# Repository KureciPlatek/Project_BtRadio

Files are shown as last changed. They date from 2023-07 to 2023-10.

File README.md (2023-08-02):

# Vintage radio Philips Hurricane De Luxe with Bluetooth

This project is about renewing an old (and wonderful) Phillips Hurricane De Luxe 50IC361.
It still uses loudspeaker, but inside is everything new. It becomes new and modern audio stream source

The aim is also to have fun with new technologies and train HW/SW skills as well as project management. 

## The radio:  
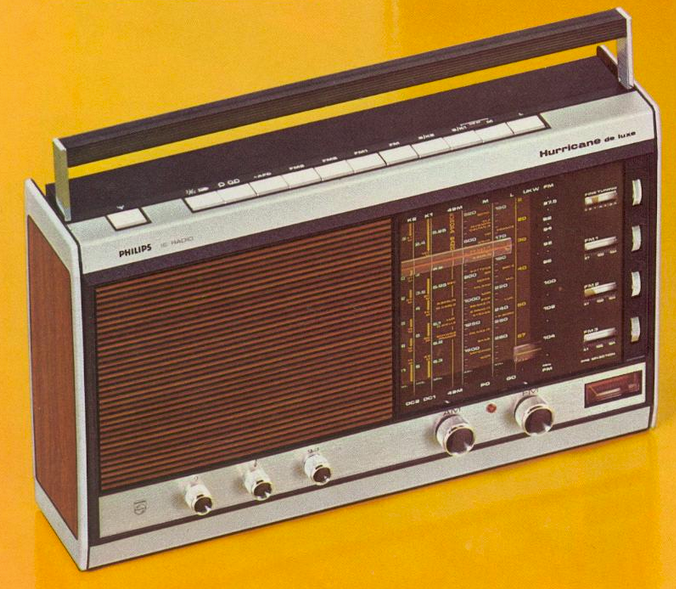
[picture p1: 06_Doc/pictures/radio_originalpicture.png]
Philips Hurricane de Luxe Philips 50IC360


## Technology used:  
- Bluetooth chip RN52 (old but had it on a shelf that was getting dust for years)
- FM demodulator from Silicon Labs: si470x which is able to demodulate FM radio emission and decode RDS (Radio Data System)
- Epaper 5.8" from Waveshare, they actually fit almost perfectly where frequency panel was
- Rotary encoders to give "digital" signals to central/control unit
- RP2040 as central unit because it is cheap, has double core features and suits perfectly the need of this project
- KiCad for HW development
- CMake/Pico SDK for software development
- git for versionning and project management
- Use ARC42 documentation format to present project and explain architecture

For the management part, full development is managed with a TICKETS.md textual file. It is split into 3 parts: SYS, HW and SW: SYStem, HardWare and SoftWare. No particular mechanical development was done so no section for that is made (it could exists to interface PCB into old Phillips radio though).

All details here:
- Introduction, goals and constraints: [ARC42_IntroAndGoals](./00_Requirements_Inputs/ARC42_IntroAndGoals.md)
- Contextes and solution strategy: [ARC42_SolStrat](./01_Analysis/ARC42_ContextAndScope.md)
- Architecture description: [ARC42_Architecture](./02_Architecture_Modelisation/ARC42_architectureMain.md)
- Project decisions, risks and technical debts: [ARC42_DecisionsRisksDebts](./02_Architecture_Modelisation/ARC42_RiskDebtDecisions.md)

## Required:

- Raspberry pico sdk
- cmake
- gnu c compiler toolsuite

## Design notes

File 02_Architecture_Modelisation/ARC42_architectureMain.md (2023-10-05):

# Architecture description

This chapter describes the main architecture, first as a system view, complying to all requirement, quality goals and constraints.
Then it is split into Software, Hardware and Mechanical topics and architectures.

All issues and tickets about hardware and software topics are listed in [TICKETS](../00_Requirements_Inputs/TICKETS.md) file. As mechanical topics are rare and don't require many effort. No mechanical tickets are written.

## System architecture structure design

System architecture

|Module| Purpose/Description| Interface|Technology| Nickname |
|:-:|:-|:-|:-|:-|
|Central Unit| Contains the software, interfaces almost all other modules and is the main entity of this system| All possible interfaces needed by other modules | RP2040 on a Raspberry Pico board | CU |
|Rotary encoders| Button interfaces with human. They can forward human commands to central unit: turned direct, turned indirect or pushed (they possess a push button too.). This module also gathers legacy push-buttons of radio which will be re-used to select radio mode | GPIOs are required, 3 per Rotary Encoder | Iduino Rotary Encoders |RE |
|Bluetooth Chip| Provide a Bluetooth connection to audio stream sources, retrieve information about connected device and track metadata and provide an audio differential output | GPIOs and UART are needed to control this device | RN52 | BT|
|FM demodulator | Can demodulate FM radiowaves and provide the audio output. It is also able to decode RDS metadata| I2C and UART are required to control this device | si470x| FM|
|e-paper screen| Is used to print all info, status, any kind of output judged as relevant for human user. Like track metadata, FM status or BT status | SPI is required | Waveshare e-paper 5.83" | EP |
|Audio Stage| Drives the 8 Ohms loudspeaker and switches between FM and BT modules depending on what CU orders | One GPIO is required | TPA6112A, PMA8302, TS5A2234 | AS |
|Power Management| Provide power supply to system. Is able to generate a 3.3V from either a 5V power supply, or a 12V power supply (battery)| USB plug and wires | LM317, NXE2S1205MC DC-DC converter |PM|
|Auxiliary Connector| Most of modules have debug interfaces as well as additional interfaces available. They are all gathered here, for future purpose if needed. SWD and UART of RP2040 are available here for debug| SPI, UART, GPIOs | Simple headers | AUX |

**Note:** This system view is also deploymen-view like. Therefore, no deployment view will be described in further documentation.

## Software architecture structure view

The software structural architecture is quite straigth-forward, as it doesn't have any particular complexity. Therefore, a simple layer architecture is quite enough:  

Software architecture

Modules Pico SDK and RP2040 Hardware are actually "out of project" as they are already made, external modules. They are part of the structural architecture, but no work is to be done here.

### Detailled description of modules:

|Module| Desription| Software directory |
|:-:|:-|:-|
|Application (main)| main module, (starts with main.c in program). Describes the wished radio behavior and uses the other modules beneath it to realize it | [Software/code](../03_Development/Software/code/) |
|re_Buttons| Driver for rotary encoders, it provides handles to whom want to be notified if a rotary encoder was turn, in which direction it was turned and if push button was triggered. For legacy buttons, as only a direct GPIO state is enough, no code was added for them. They will be monitored directly by the Application (main module) | [Software/code/re_Buttons](../03_Development/Software/code/re_Buttons/) |
|bt_rn52| Driver for Bluetooth chip Microchip's RN52. It uses UART and GPIOs to configure the RN52 chip, send command and read results. I2S inteface is not used. Audio stream is directly outputed to differential output | [Software/code/bt_rn52](../03_Development/Software/code/bt_rn52/)|
|fm_si470x| Driver of si470x chip, which provides FM demodulation. It uses I2C and GPIOs interfaces to configure, control and retrieve RDS data from Si470x chip |[Software/code/fm_si470x](../03_Development/Software/code/fm_si470x/)|
|rdsDecoder| Provide tools to decode RDS frames notified by si470x. This module is actually only used by fm_si470x module and may be integrated to it |[Software/code/rdsDecoder](../03_Development/Software/code/rdsDecoder/)|
|hmi_ePaper| Driver of Waveshare e-paper. It mainly uses already provided driver from waveshare, which was a little bit reconfigured and cleaned for lightness and simplicity |[Software/code/hmi_ePaper](../03_Development/Software/code/hmi_ePaper/)|

**Note:**  
The whole code is written in C and uses CMake for compilation.

## Software architecture runtime view

This chapter describes, either with sequence, process or state machine UML diagrams, module's behavior as well as application's usecase.

### Application usecases

Rotary encoders allow infinte turn in direct or indirect rotating direction. Two rotary encoders are used for functional requirements described in [Intro and goals](../00_Requirements_Inputs/ARC42_IntroAndGoals.md).  
Depending on the mode (Bluetooth stream or FM stream) both of those rotary encoders enters a different behavior.  
The whole application runs as a state machine, depending on which mode is active (audio stream or FM demodulation). It is a simple state machine switching between mode BT (Bluetooth) and FM (FM demodulator). How user interacts with radio and how radio reacts is described below:  

#### Buttons and rotary encoders

**[Usecase 1 - standard audio stream control](../00_Requirements_Inputs/ARC42_IntroAndGoals.md)**  
**[Usecase 4 - Seek FM station](../00_Requirements_Inputs/ARC42_IntroAndGoals.md)**  

|Rotary encoder| Mode | Direct rotation | Indirect rotation | Push button |
|:-:|:-:|:-:|:-:|:-:|
|RE_1| Bluetooth | Volume- | Volume+ | Mute/Unmute |
|RE_1|FM demodulation| Same | Same | Same |
|RE_2| Bluetooth | Previous track | Next track | Play/Pause |
|RE_2|FM demodulation| Previous Station | Next Station | Select favorite ([behavior here](#select-favorite-fm-channel)) |

**[Usecase 2 - connect modern device](../00_Requirements_Inputs/ARC42_IntroAndGoals.md)**  
Phillips radio has many push buttons on top of it. Some are push/hold/exclude, some are just push/hold and some are just push.

Button | Place | Style | Role |
|:-:|:-:|:-:|:-:|
|X    | Far left | Push/Hold/exclude | Select bluetooth streaming |
|IX   | | Push/Hold/exclude| Select FM demodulation|
|VIII | | Push/Hold/exclude| none |
|VII  | | Push/Hold/exclude| none |
|VI   | | Push/Hold/exclude| none |
|V    | | Push/Hold/exclude| none |
|IV   | | Push/Hold/exclude| none |
|III  | | Push/Hold| none |
|II   | | Push/Hold| none |
|I    | Far right | Push Hold| On/Off |

**[Usecase 3 - Select and save FM station](../00_Requirements_Inputs/ARC42_IntroAndGoals.md)**  
Rotary encoder 2 has a specificity when entering "Select Favorite". There are many different stations and be able to select a favorite is nice. Saving a favorite should be possible, as station differs from place to place.

When clicking PushButton of RE_2 in FM mode, the following behavior appears:  
Behavior select and save FM station

### FM behavioral

@todo - also may need a bugfix when seeking/tuning and so on

### BT behavioral

No particular behavioral, look at doxygen API documentation

### RE behavioral

Rotary encoders work as state machines. As soon as one of the input of rotary encoder is triggered (GPIO_A or GPIO_B), they will enter a "wait for the other input to determine direction":  

Rotary encoder behavior

### EP behavioral

[< prev (Context and scope)](../01_Analysis/ARC42_ContextAndScope.md) - [next > (Decision, Risks and Technical debt)](../02_Architecture_Modelisation/ARC42_RiskDebtDecisions.md)

## Hardware architecture view

This section provides a detailled view of circuit schematic and PCB design. There is no behavioral described, as it may be found in the corresponding datasheet of components and will only be a re-write of what already exists.

### Schematic

Schematic is divided into thre sheets: a main sheet with modules. An audio amplifiying stage sheet and a connectors to legacy push buttons sheet.

#### Main schematic
Main schematic

#### Audio amplification stage schematic
Audio stage

#### Legacy push buttons connectors schematic
Legacy push buttons

### PCB
After routing, PCB has the following face:  

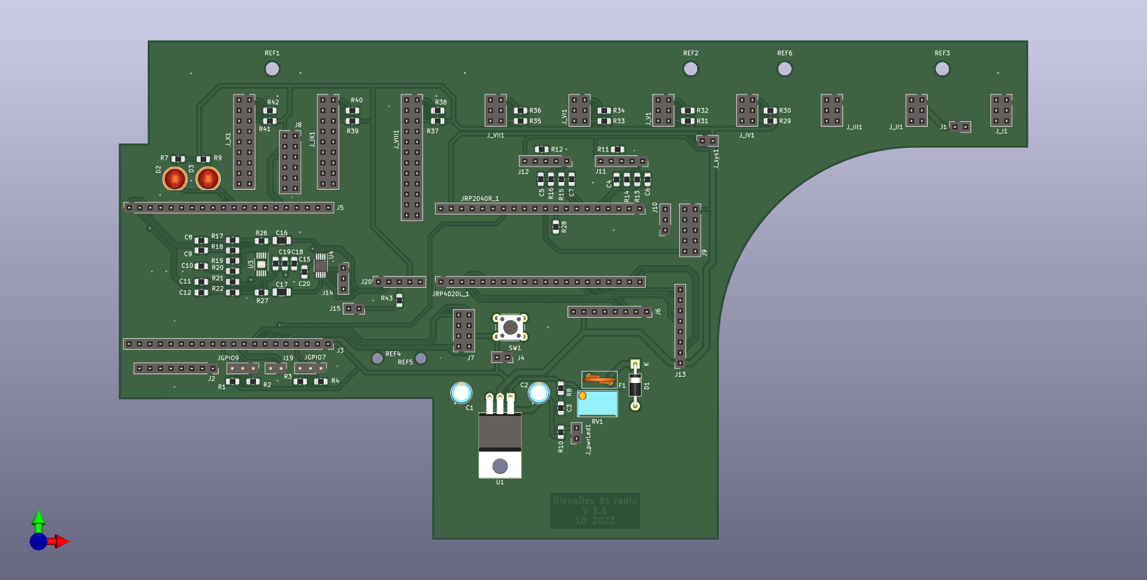
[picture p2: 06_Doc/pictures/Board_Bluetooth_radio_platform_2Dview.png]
PCB 2D view


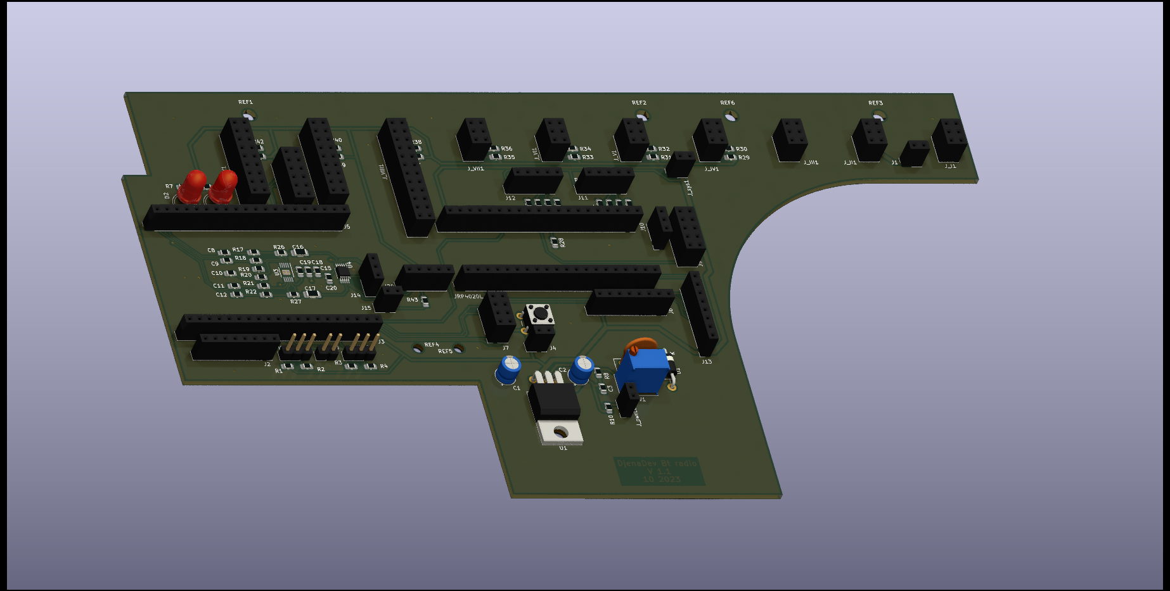
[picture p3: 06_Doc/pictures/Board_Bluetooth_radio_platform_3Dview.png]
PCB 3D view


@todo: holes, form and connectors placement dimension measure list.

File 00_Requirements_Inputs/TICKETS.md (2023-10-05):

# Project Bluetooth radio

## INTRO:

In this file are listed all tickets/todo to be checked and done. Another program should be used but it will suffice for now.

It is sorted by:

|level|description|Identification prefix|comments|
|:-:|:-|:-:|:-|
|system|means application, behavior, user experience, non technical topics|SYS_||
|software|pure software, can be bare metal, like driver, to scheduling items|SFW_||
|hardware|everything that is outside the DSP and are linked to electronic development|HDW_||

*__Note:__  
the issue identification is a prefix followed by a number which is the issue identification number.   
For example: SYS_14 is the system level issue 14*

*__Note:__  
When closing an issue (rejected or resolved), please add the SHA-1 number from git to identify it and track it back.*

***
## SYSTEM ISSUES

**New issues:**  

|Issue| Description | state |
|-|-|-|
|SYS_13| *Architecture* Add clean doxygen API documentation of drivers to architecture documentation |NEW|
|SYS_15| *Architecture* Add add link to requirements/constraints, everywhere in project description |NEW|

**Work In Progress issues:**  

|Issue| Description | state |
|-|-|-|
|SYS_11| *System* Integrate all (obviously) | WIP - Breadboard done, integration of RE, BT and EP done. FM module will be deactivated at the beginning |
|SYS_12| *Architecture* Write down all algorithms and interrupt routines in UML diagrams/pseudo code |NEW|

**Resolved issues:**

|Issue| Description | state |
|-|-|-|
|SYS_3| *FM tuner* Check for a good AM/FM demodulator, some integrate RDS and RBDS, like Si4703 (look for Sparkfun breakout board) | DONE - use of Si4703 breakout board |  
|SYS_6| *HMI* Use of ePaper screen with RP2040 Pico https://www.berrybase.de/5-83-zoll-e-ink-display-modul-fuer-raspberry-pi-pico-648-480-schwarz/weiss | DONE |
|SYS_2| *Multiple PCB project* As some Bluetooth radio may stay on furnitures, like the vintage one, a direct plug to 220V network and a stronger audio amplifier is possible. How to manage two kind of PCB should be decided | DONE - create two PCBs |
|SYS_7| *Audio amplification* Check if Class D is sufficient and remove the TPA6112A2 | DONE - keep TPA6112A2 as it is wonderfully powerful with it |
|SYS_4| *HMI* List all input and features that system shall have: AM/FM switch, Bluetooth pair and connect, maybe a small screen | DONE - AM/FM in option, rest is all integrated |
|SYS_5| *HMI* Test and assignate available push button and rotary button of Phillips to interface of RN52 | DONE - Look at document  Architecture->Behavioral->hmi_description.md |
|SYS_8| *Project versioning* Add a github repository | DONE - but lose of old git repo history |
|SYS_14| *Architecture* Add application main usecases and link them to runtime view of software architecture |DONE - Add of Usecase diagram and its corresponding behavioral diagrams|
|SYS_9| *HMI* Check that buttons of Phillips radio are good: maybe button on far right is just push and not push/hold | DONE - Button on far right is only push but not hold. Start of radio is now on main button II |

**Rejected issues**

|Issue| Description | state |
|-|-|-|
|SYS_1| *Use of a battery* To use the radio without any power supply, a battery must be added. It implies however some constraints on the available voltage on the PCB. This limits the choice of audio amplifier available. Create a votlage which is bigger than the one from power supply is quite complex and may lead to development complexity | REJECTED - Too complex for Mark I futur use: RP2040 Plus Based (contains a Lithium manager) |
|SYS_8| *HMI* Add RealTime clock and Date for more infos on screen | REJECTED - will take too much time |
|SYS_9| *Memory* Add external flash like a W25Q16JV (SPI, 133 MHz) or an M25P16 (SPI, 75 MHz) | REJECTED - Should be fine without. Otherwise, our system is too complex |
|SYS_5| *Architecture* Create block diagram of main element with their interfaces | REJECTED - Carry on with project and get it done |
|SYS_10| *Proj_DVA* Add AD8248 circuit and PCB to project | REJECTED - one system at a time |

***
## SOFTWARE ISSUES

**New issues:**  

|Issue| Description | state |
|-|-|-|
|SFW_24 |*Doc* Cleanup and generate Doxygen API | NEW |
|SFW_29 |*FM_module* FM demodulator has a strange reaction to seek or tune and can't find any channel/station | NEW |

**Work In Progress issues:**  

|Issue| Description | state |
|-|-|-|
|SFW_14 |*FM_module* Add behavioral in application | WIP - half commented out |
|SFW_7 |*Architecture* Describe code as a waiting state machine to recieve "internal interrupts", which are tokens | WIP - partially implemented, they way inputs from modules are processed should be checked |
|SFW_3 |*Architecture* Cleanup git repo, create clean architecture of project | WIP - cleanup code for useless and commented lines |
|SFW_28| *BT_module*, *FM_module* Deactivate interrupts of module when not in use | WIP - only UART and GPIO interrupts are activable/deactivable |

**Resolved issues:**

|Issue| Description | state |
|-|-|-|
|SFW_1 |*e-Paper* Add test and interface to RpPico with assigned pins | DONE - use of example in /home/jeremiegallee/Pico_epaper_example/ |
|SFW_10 |*Coding* synchronize naming with architecture (prefixes) bt_rn52 for bluetooth module and fm_si470x for FM module, re for rotary encoders and epaper for HMI | DONE - set bt_, fm_, re_ and ep_ prefixes |
|SFW_8 |*BT mode* Create high level API to communicate with RN52 module through UART and AT commands | DONE - already implemented |
|SFW_18 |*FM mode* Restructure fm_application and fm_api as they have common role and SOLID principles not fully respected (call only from one place of the module, not 2) | DONE - renamed functions prototypes and file names |
|SFW_5 |*Architecture* Create main state machine and its sub state machines | DONE - Main state machine processes new inputs and execute corresponding actions |
|SFW_9 |*BT mode* Add feature to print "ready to pair", "connected" and so on to epaper screen | DONE - keep it simple and just check if connection bit of rn52 status registers is still set |
|SFW_25 |*EP_module* EP_module provided API can't load new lines and keep the old ones. Way to use it should be different | DONE - call Paint_ClearWindows() to clean one line only |
|SFW_4 |*Architecture* Create RotaryEncoder interrupts | DONE - Test success |
|SFW_13 | *BT mode* Add GPIO2 interrupt (which implies to send Q to radio) | DONE - Q is sent to RN52 after GPIO2 interrupt |
|SFW_15 | *Main* Take care of radio project init and selection of mode with GPIOs | DONE - GPIOS which requires interrupt are gathered together in hal_radio module |
|SFW_19 |*e-Paper* Add clean API for rest of the application | DONE |
|SFW_20 |*All* Make project compile. Maybe restart full project CMakes as they are strange | DONE - use simple CMake structure |
|SFW_16 |*REx* Add timeout before other GPIOs may "react". Aim is to entprellen | DONE - Not perfect but enough for requirements |
|SFW_21 |*RP2040* Check this stuff with double core. We may have pbm with interrupts affected to a core | DONE - Only core0 is called. Nothing on core1 right now |
|SFW_17 | *BT mode* Add processing function to analyse retrieved data from RN52's UART comm | DONE - RN52's comm had to be hugely cleaned up |
|SFW_27 |*EP_module* Check why is epaper having this cathodic tube like effect (imageBuffer not all 0?) | DONE - had to clean heap where image buffer was saved |
|SFW_26 |*EP_module* Add screenClear() procedure before shuting down. Otherwise, pixels will stay active and may damage epaper | DONE - Use of ep_deactivate() when no HW mode is selected |
|SFW_2 |*FM_module* Strange freeze after first seek up/down. Debug with PicoProbe | DONE - A too small array was given and it was overwriting out of bonds on the stack |

**Rejected issues**

|Issue| Description | state |
|-|-|-|
|SFW_12 |*FM mode* Manage FM as a handle too | REJECTED - use getters and setters instead |
|SFW_11 |*REx* Add delay between each rotary A or B key | REJECTED - Control of RE is not perfect but enough for now |
|SFW_22 |*RP2040* [Optional] use of FreeRTOS for multitasking | REJECTED - Do it in a second version |
|SFW_23 |*Structure* Modify and clean hal_main for GPIOs IRQ as it is too quick and dirty | REJECTED - Do it in a second version |

***
## HARDWARE ISSUES

**New issues:**  

|Issue| Description | state |
|-|-|-|

**Work In Progress issues:**  

|Issue| Description | state |
|-|-|-|

**Resolved issues:**

|Issue| Description | state |
|-|-|-|
|HDW_3| *Programming protection* To avoid too many components on board. Use of Waveshare USB to TTL. But it must be set to 3.3V because will be directly connected to RN52 power supply| DONE |
|HDW_2| *Programming interface* The RN52 must be programmed through an UART interface. The board must be disabled from voltage, so that only Waveshare USB to TTL may power the board and program it through UART | DONE - all RN52 boards to last firmware and UART connector added |
|HDW_9 | *Structure* Organize Kicad project into sheets, one sheet per module of board | DONE - use hierarchical sheet |
|HDW_12| *Class A audio amplifier* generate current driven class A audio amplifier circuit | DONE - but will be unused firstly |
|HDW_4 |*Board* create footprints for buttons of old Phillips radio | DONE - footprints are simple 2.57 mm pitch header footprints |
|HDW_14| *Structure* Rename all labels for a hierarchical and structured naming. Do it with sheets too | DONE |
|HDW_6 |*Board* Check for debug interface with RaspPico debug probe and BlackMagicProbe | DONE - Picoprobe will be used instead of BMS. So install Picoprobe connector with BMS style|
|HDW_8 |*Powersupply* Find circuit to connect to 220 VAC directly. It will provide the advantage to generate +5V, +3V3 and +30V for bigger audio amplifiers | DONE - Use an LM317 and buy/use a "good ol'" 12V power supply. RP2040 supplied through Vsys (main power input) |
|HDW_15| *Schematic* Add all values to passive R and C elements | DONE |
|HDW_10| *Housing* Create connectors for each button/selection on body housing | DONE - NO/NC connection are available on Phillips 50IC361 datasheet |
|HDW_16| *Schematic* Add e-paper display connector to board | DONE - subsheet created with connectors |
|HDW_18| *Schematic* Change power management symbols for ERC check success | DONE - change earth to GND symbol and issue lot of minor changes |
|HDW_20| *PCB* Check that all boards are well placed (direction of pins and connectors) as well as they have enough mechanic place | DONE - had to increase brightness of RN52 Sparkfun board |
|HDW_21| *PCB* Check size of holes for buttons header. Maybe the legacy component doesn't fin inside it | DONE - They fit, but only from one side |
|HDW_24| *PCB* Add name and version on board | DONE |
|HDW_17| *Schematic* Add list of elements that are not on PCB, like Jack barrel and heat sink | DONE - ordered heat sink and USB plug |
|HDW_23| *PCB* CHeck minimal via and wire brigthness allowed by JLCPCB | DONE - JLCPCB offers up to 0,127 mm wire thickness |
|HDW_33| *PCB* LM317: move so that it may be mounted horizontally | DONE - all pieces moved |
|HDW_32| *Powersupply* Put potentiometer for voltage regulator | DONE - added in schematic and PCB |
|HDW_31| *Powersupply* Add potential DC-DC downconverter for 12V battery pack | DONE - added in schematic and PCB |
|HDW_34| *PCB* Move all button resistance down to few mm as they will disturb mechanical place of button holders | DONE - all resistance moved |
|HDW_36| *PCB* Add boarder lines for cut | DONE - Had to remove fully drawn circle from edge.cut layer |
|HDW_25| *PCB* Install holes for screwing/monting on old radio | DONE - add mounting holes for PAM8302 too |
|HDW_38| *All* Fix UART communication wires. BT_Rx is actually on GPIO4 and BT_Tx on GPIO5 | DONE - modify schematic and PCB |
|HDW_41| *Routing* BT, EP and FM modules have been wrongly routed. Correct PCB and Software | DONE - changed communication lines of UART and I2C for BT, FM and EP modules |
|HDW_45| *Powersupply* Remove 12V transformer, go only on 5V | DONE - removed in schematic and PCB |
|HDW_39| *Schematic*  RP2040 actually has very low internal pull-up/down. 100k is way too high and signal at RP2040 pin is too small. Check pull-up and pull down resistance of 10k or 4,7k are ok | DONE - in commit 45d533c HDW_41 |
|HDW_44| *PCB* Check that push buttons are good, only on dry contact way, but check that a pushed button is either high or low active, without any perturbations | DONE - push buttons are gnd in normal position and to Vcc when pushed |
|HDW_42| *PCB* Move mechanical place of push buttons, they are biased of few millimeters, add a system to fix/set vertical place of mechanical buttons at production (set/adapt it at mounting) | DONE dimensions were measured on final target for mounting |
|HDW_50| *PCB* Check mechanical place of mounting screws if they fit to the right place | DONE mouhting screw are now in the right place mut may be small |
|HDW_49| *PCB* Check that mechanical place for eval-boards fits | DONE - all good |
|HDW_51| *Schematic* Change on/off button to connector II or more as I is not push/hold but just push | DONE - moved to push button II and update of PCB |
|HDW_54| *All* Update BOM and buy parts | DONE - had to change C15 and C16 from 0805 to 1210 footprints |
|HDW_53| *PCB* Modify layout of preamplifier and switch to improve gnd path | DONE - improved gnd panel and placement |
|HDW_55| *PCB* Improve grounding of F and B copper ground panes by connecting push buttons jumper unused vias to ground | DONE |
|HDW_37| *PCB* Send PCB to production, gather last required components, sold everything together | DONE - go to V1.1, V1.0 is not good |
|HDW_7 | *Audio ampl* Order and test the TS5A2234 analog audio switch | DONE - works fine |
|HDW_19| *RP2040* Check for powering if all good | WIP - test a 3V3 on Vsys on power supply (no microUSB load) | DONE - seems to work |
|HDW_22| *Schematic* Check that with the actual schematic connection, RP2040 can control epaper | DONE - routing is good |
|HDW_28| *Powersupply* Test that LM317 do bring enough power to supply board at full need | DONE - Real men test only in production |
|HDW_30| *All* Create clean mock-up with breadbord and elements check that all HW works | DONE - Real men test only in production |
|HDW_52| *test* Check that soldered components on Bluetooth and RP2040 are good. Solder all and verify | DONE - Real men test only in production |
|HDW_43| *PCB* Re-write mechanical edges of PCB as the actual do not fit in radio | DONE - printed on paper and V1.1 is ready for production |

**Rejected issues**

|Issue| Description | state |
|-|-|-|
|HDW_1| *Linked do SYS_1* Battery management system must be found as well as a battery. A reloadable one must be chosen which allows an audio amplifier to work with 10 Watts minimum | REJECTED - too complex |
|HDW_14| *Modularity* Add link to ClassA amplifier and ClassD. At PCB creation, HMI+RP2040 parts will be doubled, Class A and Class D not. Split PCBs into two parts, one with Audio ampl, one with the rest. | REJECTED - too complex, maybe a powerful class D will be used like the TPA3223 |
|HDW_5 |*Board* Add connectors for exclusive push buttons of vintage and phillips radios | REJECTED - Double with ticket HDW_4 |
|HDW_11| *Class A audio amplifier* check that all component from current's driving class A amplifier exists | REJECTED - Class A will take too much time to develop |
|HDW_13| *Breakout boards* Some of the modules are from breakout boards. Add mechanical holder for them | REJECTED - No need for that. Header will be fine |
|HDW_26| *PCB* - *Proj_DVA* Add PCB of AD8428 evaluation board | REJECTED - one project at a time |
|HDW_29| *PCB* Add testpoint on many lines as it will help modify lines if needed | REJECTED, will find solutions without |
|HDW_27| *Schematic* - *Proj_DVA* Add schematics of AD8428 evaluation board. Design different topologies to select best one | REJECTED - one project at a time |
|HDW_40| *Powersupply* DC-DC converter 12 to 5 volts from MURATA is not always available and Wuerth Elektronik provides wome acceptable solutions. Add branch or schematic to manage both configurations | REJECTED - Do it in a second version |
|HDW_46| *Powersupply* Add SparkFun Battery Babysitter based on BQ24075 and BQ27441-G1A | REJECTED - finish the project |
|HDW_47| *Powersupply* Check if SparkfunBattery Babysitter is enough for 3.3V power supply | REJECTED - finish the project |
|HDW_48| *Powersupply* Add LiPo battery 1250 mAh | REJECTED - finish the project |

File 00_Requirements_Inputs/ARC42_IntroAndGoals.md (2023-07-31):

# Introduction and goal

The aim of this project is to use an old radio Philips Hurricane de Luxe and connect it to modern audio channels so that we may stream music on it. The loudspeaker is still good. Another aim is to train in technologies such as RTOS programming, schematic and PCB design as well as project management.

## Functional requirements:

|ID|Description|
|:-:|:-:|
| FR_1 | Play audio from a modern audio source technology so that we shall use it with music stream application |
| FR_2 | Still be able to demodulate FM audi source and select between modern stream (*FR_1*) and FM radio |
| FR_3 | (*OPTIONAL*) Be able to decode DRS from FM channel should be possible |
| FR_4 | Control volume level and select audio source: FM or modern stream |
| FR_5 | (*OPTIONAL*) Be able to use it without a permanent power supply (be nomad) |
| FR_6 | Save FM stations in favorites and select them after a radio restart |

**Use case diagram:**
Use case diagram

|Usecase|Name|Description|
|:-:|:-|:-|
|usecase 1| Typical audio stream control | Provides typical audi controls, like next track, previous track, play/pause, volume control, etc... |
|usecase 2| Connect modern audio stream| User is able to connect a "modern" device, like his smartphone, to the system and to stream audio on it|
|usecase 3| Save and select FM stations| User may save a prefered FM station to a list of 5 presets and select them after a radio restart (power off). This favorites list shall save the FM frequency, and if possible (*OPTIONAL*) FM station should have their name saved too |
|usecase 4| Seek a station on FM radiowaves | User shall be able to trigger a seek on FM band in a direction (frequency increasing or decreasing) and radio shall be able to stop on a "correct" station. Correct means, audio quality is acceptable |

## Quality goals:

There are no special quality goals in a first phase as it is:  
1) A project for fun
2) To test different technologies
3) No special certification has to be done and it won't be sold

Some are nevertheless described, and are all optional

|ID|Description|
|:-:|:-:|
|QG_1| **Performance**: radio should be at least quite stable and not bug all the time |
|QG_2| **Small footprint**: radio should keep it power consumption reduced as we are not building a Ghetto Blaster (could be fun though) |

## Stakeholders:

None, except me only. Benevolent dictator for life

## Constraints

List of all constraints limiting solution choices and strategies. Either selected by me or are induced by actual situation

### Organizational constraints
|ID|Description|
|:-:|:-:|
|OC_1| Work alone and as a side project, means limited time of development|
|OC_2| Budget is limited as it should not be an expensive radio, but more for fun|

### Technical constraints
|ID|Description|
|:-:|:-:|
|TC_1| As Android and iPhone are the most knwon sources of audio stream, the system must be compatible with their technologies |
|TC_2| PCB has to fit in radio and respect its mechanical fixation points. The aim is still to use the old boxing and interface of the Philips radio |
|TC_3| (*OPTIONAL*) As it mechanically perfectly fits and is quality is still good (tested with direct plug on differential input), the system should use the old 8 Ohms 2,5 Watts loudspeaker |

[< prev (README)](../README.md) - [next > (Context & Scope)](../01_Analysis/ARC42_ContextAndScope.md)

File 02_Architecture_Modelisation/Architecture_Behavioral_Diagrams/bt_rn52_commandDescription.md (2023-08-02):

# RN52 Bluetooth communication reference and info

RN52 Bluetooth chip may be controlled and data from it get/set with a set of AT commands synthax  

For each command:
When a command is issued, RN52 module responds with an encoded 2-byte 
stream of ASCII hex data terminated by the `\r\n`

## RN52 available commands for version V1.16
### SET COMMANDS 

|AT cmd| format | Description |
|:-:|:-|:-|
|`S-`|<text>  | Serialized Name|
|`S|`|<hex16> | Audio Settings|
|`S^`|<dec> | Auto Power Off timer|
|`S%`|<hex16> | Extended Features|
|`SA`|<dec> | Authentication Mode|
|`SC`|<hex24> | Class of Device|
|`SD`|<hex8>  | Discovery Mask|
|`SF`|1 | Factory Default|
|`SK`|<hex8>  | Connection Mask|
|`SM`|<hex32> | Microphone Gain|
|`SL`|<hex32> | Line Input Gain|
|`SN`|<text>  | Name|
|`SP`|<text>  | Pin Code|
|`SS`|<hex8>  | Speaker Level|
|`ST`|<hex8>  | Tone Level|
|`SU`|<hex8>  | UART Baudrate|
|`STA`|<dec>  | Connection Delay(ms)|
|`STP`|<dec>  | Pairing Timeout(s)|

### ACTION COMMANDS
|AT cmd| format | Description |
|:-:|:-|:-|
|`+`| |Disable,Enable Local Echo|
|`@`|<0,1> |Disable,Enable Discovery|
|`#`|<0,1> |Accept,Reject Pairing Passkey|
|`$`| |Enter DFU Mode|
|`D`| |Dump Configuration|
|`K`|<hex8> |Disconnect|
|`M`|<0,1> |Mute Active Call|
|`Q`| |Connection Status|
|`R`|1 |Reboot|
|`U`| |Reset Paired Device List(PDL)|
|`V`| |Firmare Version|

### AVRCP COMMANDS
|AT cmd| Description |
|:-:|:-|
|`AV+` | Volume Up|
|`AV-` | Volume Down|
|`AT+` | Next Track|
|`AT-` | Previous Track|
|`AP`  | Play/Pause|
|`AD`  | Track Metadata|

### CONNECTION COMMANDS
|AT cmd| format | Description |
|:-:|:-|:-|
|`A`|<text> |Initiate Voice Call|
|`AR`| |Redial Last Dialed Number|
|`B`| |Reconnect Last Device|
|`C`| |Accept Incoming Call|
|`E`| |Drop/Reject Active Or Incoming Call|
|`F`| |Release All Held Calls|
|`J`| |Accept Waiting Calls And Release Active Calls|
|`L`| |Accept Waiting Calls And Hold Active Calls|
|`N`| |Add Held Call|
|`O`| |Connect Two Calls And Disconnect The Subscriber|
|`T`| |Caller ID Information|
|`P`| |Initiate Voice Recognition|
|`X`|<0,1>  |Transfer Call Between HF And AG|

Q results:
0 iAP wireless active connection to remote device
1 SPP active connection to remote device
2 A2DP active connection to remote device
3 HFP/HSP active connection to remote device
4 Caller ID notification event from audio gateway
5 Track change event notification

## GPIOs needed for UART communication 
GPIO9
- drive GPIO9 low for CMD mode
- drive GPIO9 high for DATA mode
-> we use CMD mode only
GPIO4:  Reset to factory settings
GPIO7:  Driving this pin low sets the UART baud rate to 9,600 bps. By default the pin is high and the UART has a baud rate of 115200 bps
GPIO2:  Toggles from high to low for 100 ms to indicate that the module’s state has changed

## UART communication 
- 115,200 Kbps
- 8 bits
- Parity: none
- Flow control: enabled (but seems to work better without)

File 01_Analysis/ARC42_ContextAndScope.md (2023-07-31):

# Context and scope

In this part are explained the context in which the device is, on a business point of view (features, interactions, qualities required) as well as on a technical point of view, which means which technologies are used and where

## Business context

System business context

|Entity|Purpose/Interaction|
|:-:|:-|
|User| Controls the radio. It can execute nextPrevious track, control volume level, search FM channel or save/search one, etc... User has also a second channel, which is from our system, to the User and it provides information about status, track played and so on...|
|FM sender| Is the FM sender antenna, it provides different station and use the standard FM network|
|Modern audio stream| Is the source of audio stream, it must respect constraints described in part I|
|Speaker| Is the speaker to output audio |

## Technical context

System technical context

|Entity|Technical interface|
|:-:|:-|
|User| Uses buttons and screen to interact with radio|
|FM sender| Will be demodulated with a modern FM demodulator chip which also provide RDS decoding |
|Modern audio stream| Use of Bluetooth protocol to stream audio on radio. This protocol has the advantage to be massively integrated in actual private portable devices|
|Speaker| Keep the loudspeaker as described in technical constraints. Use of an 8 Ohms 2-3 Watts differential amplifier |

## Solution strategy

### Control radio
For the interaction with human user, rotary encoders were selected. They can mechanically easily be mounted on Philips Radio. Old potentiometers are more complex to interface with the Bluetooth chip and modern FM demodulator. Indeed, those have industrial communication interfaces like I2C, SPI or UART and requires encoded binary messages to be controlled. Therefore, the action to turn button, must be first sent to a central unit, which convert the rotation direction into a command, understandable for the sub entity (Bluetooth chip, screen, FM demodulator...)

Rotary encoders generally also offers a push button when pushing their knob. It allows to have for all rotary encoders, the capacity to send 3 different signals to a microcontroller:
 - Direct rotation
 - Indirect rotation
 - Button pushed

Legacy push-buttons will however be re-used (**TC_3**), as they are simple contact push-buttons on which a binary info may be sent to our system. They will be used to select radio mode, like switch between audio source, or power supply, or anything like that.

### Get radio status
Use of an e-paper screen to get info from radio (status, track metadata, etc...) This kind of screen is actually quite nice to use and present an advantage about power consumption. Waveshare epaper 5.83" was selected as it provides a ready-to-use API which is programmed in C.

### Modern audio stream
Use of AirPlay was rejected, as it would have made the radio too complex, increase development time and present the disadvantage to require a Wifi network to stream music on it. Airplay also has the disadvantage to have sometimes 1 or 2 seconds delay, as well as a long start-up time to connect to WiFi.  
Bluetooth is the best option as it is widely used in personal portable devices and has with the time evolved and present acceptable sound quality. Bluetoot chip RN52 from Microchip was selected as it is quite easy to integrate and presents a differential audio output.

### FM demodulator
si470x From Skyworks was selected for this role. The choice was made because Sparkfun propose an already finished hardwre module

### Audio output
To comply to consumption quality goals, and as sound quality of the project is not the main topic, a class D audio amplifier was selected. The PMA8203, which offers excellent results and a powerful sound, even when it is only 2.5W! It interfaces itself quite good with the old paper loudspeaker of the Philips radio (impedance and output power).  
 - For Bluetooth audio output, a TPA6112A 150 mW preamplifier is wired, prior to class D amplifier  
 - For si470x, it is directly plugged onto PMA8302 audio input.  
 - To switch between FM and Bluetooth audio sources, an audio switch from Texas Instruments TS5A2234 is placed between the different audio sources and has its output wired on PMA8302 input.

**Specific info about audio switch**:  
There is something quite welcome, it is the deactivation of RN52 and si470x, they are inverted. Which means, the line to select audio output can also be used to deactivate/activate the corresponding audio source. 

### (OPTIONAL) Battery
As desired as a optional feature of the project, a 12V battery will also be integrated in the project. There are main 12V batteries, of many different capacity. I took an old one from ma shelf of 1100 Ah.

#### Power consumption estimation
A small power consumption estimation of the project and the longevity of the battery in worst case:
|Element | Typical/Maximal consumption|
|:-:|:-|
|Central Unit (RP2040)| 40 mA max|
|BT (RN52) | 30 mA typical |
|FM (si470x)| 20 mA max|
|Audio (PMA8302)| 2,5 W|

Consumption worst case of all units without class D:  
With margin: 90 mA @ 3V3 = 300 mW

Consumption with class D audio module (at maximum level)  
2,5 + 0,3 = 2,8 W.

Consumption with class D audio module (typical level)  
1.25 + 0,25 = 1,5 W.

Our battery has:  
12 * 1,1 = 13,2 Wh of power, which means:  

| Working time typical | Working time at full power |
|:-:|:-:|
|13,2/1,5 = 8,8 hours |13,2/2,8 = 4,7 hours|

Which is quuiiiiiiite ok.

### Our system
The main element, our system will be progtrammed with a Raspberry Pico, having an RP2040 microcontroller. This uC presents quite the quantity of advantages:
 - Dual core (interessant for RTOS training)
 - Quite cheap
 - Enough I/O to be interfaced with all elements of project
 - Has a powerful SDK well documented, which uses CMake

[< prev (Intro and goals)](../00_Requirements_Inputs/ARC42_IntroAndGoals.md) - [next > (Architecture design)](../02_Architecture_Modelisation/ARC42_architectureMain.md)

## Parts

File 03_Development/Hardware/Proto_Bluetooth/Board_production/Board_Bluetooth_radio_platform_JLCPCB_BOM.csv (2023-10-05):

Comment | Designator | Footprint | LCSC
100u | C15 | Resistor_SMD:R_0805_2012Metric_Pad1.20x1.40mm_HandSolder
68u | C16,C17 | Resistor_SMD:R_1206_3216Metric_Pad1.30x1.75mm_HandSolder
10u | C19 | Resistor_SMD:R_0805_2012Metric_Pad1.20x1.40mm_HandSolder
100n | C3,C18,C20 | Resistor_SMD:R_0805_2012Metric_Pad1.20x1.40mm_HandSolder
10n | C4,C5,C6,C7 | Resistor_SMD:R_0805_2012Metric_Pad1.20x1.40mm_HandSolder
1u | C8,C9,C10,C11,C12 | Resistor_SMD:R_0805_2012Metric_Pad1.20x1.40mm_HandSolder
10k | R1,R2,R3,R4,R11,R12,R13,R14,R15,R16,R28,R29,R30,R31,R32,R33,R34,R35,R36,R37,R38,R39,R40,R41,R42,R43 | Resistor_SMD:R_0805_2012Metric_Pad1.20x1.40mm_HandSolder
330 | R10 | Resistor_SMD:R_0805_2012Metric_Pad1.20x1.40mm_HandSolder
22k | R17,R18,R21,R22 | Resistor_SMD:R_0805_2012Metric_Pad1.20x1.40mm_HandSolder
47k | R19,R20,R26,R27 | Resistor_SMD:R_0805_2012Metric_Pad1.20x1.40mm_HandSolder
470 | R7,R9 | Resistor_SMD:R_0805_2012Metric_Pad1.20x1.40mm_HandSolder
240 | R8 | Resistor_SMD:R_0805_2012Metric_Pad1.20x1.40mm_HandSolder

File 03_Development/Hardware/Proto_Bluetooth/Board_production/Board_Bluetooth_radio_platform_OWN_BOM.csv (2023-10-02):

Comment | Designator | Footprint | Mouser ref
100u | C1 | Capacitor_THT:CP_Radial_D5.0mm_P2.50mm | own
100u | C15 | Resistor_SMD:R_0805_2012Metric_Pad1.20x1.40mm_HandSolder | 81-GRM21BR60G107ME1L
68u | C16,C17 | Resistor_SMD:R_0805_2012Metric_Pad1.20x1.40mm_HandSolder | 810-C3216X5R0J686M1B
10u | C19 | Resistor_SMD:R_0805_2012Metric_Pad1.20x1.40mm_HandSolder | 80-C0805C106J8RAUTLR
10u | C2 | Capacitor_THT:CP_Radial_D5.0mm_P2.50mm | own
100n | C3,C18,C20 | Resistor_SMD:R_0805_2012Metric_Pad1.20x1.40mm_HandSolder | 80-C0805C104J5RAC
10n | C4,C5,C6,C7 | Resistor_SMD:R_0805_2012Metric_Pad1.20x1.40mm_HandSolder | 187-CL21B103KCANNNC
1u | C8,C9,C10,C11,C12 | Resistor_SMD:R_0805_2012Metric_Pad1.20x1.40mm_HandSolder | 187-CL21B105KAFNNNE
1N4001 | D1 | Diode_THT:D_DO-41_SOD81_P10.16mm_Horizontal | own
LED | D2,D3 | LED_THT:LED_D5.0mm | C4SMM-BJY-CN3Q2352
Polyfuse 1,5A | F1 | Fuse:Fuse_BelFuse_0ZRE0005FF_L8.3mm_W3.8mm
Conn_01x02 | J1,J_pwrLed1,J_sys1,J4,J17 | Connector_PinSocket_2.54mm:PinSocket_1x02_P2.54mm_Vertical | own
Conn_01x03 | J10 | Connector_PinSocket_2.54mm:PinSocket_1x03_P2.54mm_Vertical | own
HMI_rotaryEncoder_1 | J11,J12 | Connector_PinSocket_2.54mm:PinSocket_1x05_P2.54mm_Vertical | own
Conn_01x08_epaper | J13 | Connector_PinSocket_2.54mm:PinSocket_1x08_P2.54mm_Vertical | own
Conn_01x03_fmModule_audioOutput | J14 | Connector_PinSocket_2.54mm:PinSocket_1x03_P2.54mm_Vertical | own
Conn_01x02_classD_SD | J15 | Connector_PinSocket_2.54mm:PinSocket_1x02_P2.54mm_Vertical | own
Conn_01x02_rn52_usb | J19 | Connector_PinHeader_2.54mm:PinHeader_1x02_P2.54mm_Vertical | own
Conn_01x08 | J2 | Connector_PinSocket_2.54mm:PinSocket_1x08_P2.54mm_Vertical | own
Conn_01x05_toClassD | J20 | Connector_PinSocket_2.54mm:PinSocket_1x05_P2.54mm_Vertical | own
BT_RN52_connector_left | J3 | Connector_PinSocket_2.54mm:PinSocket_1x20_P2.54mm_Vertical | own
BT_RN52_connector_right | J5 | Connector_PinSocket_2.54mm:PinSocket_1x20_P2.54mm_Vertical | own
FM_interface | J6 | Connector_PinSocket_2.54mm:PinSocket_1x08_P2.54mm_Vertical | own
BT_debug_connector | J7 | Connector_PinSocket_2.54mm:PinSocket_2x04_P2.54mm_Vertical | own
BT_extension_connector | J8 | Connector_PinSocket_2.54mm:PinSocket_2x08_P2.54mm_Vertical | own
SYS_debug_connector | J9 | Connector_PinSocket_2.54mm:PinSocket_2x05_P2.54mm_Vertical | own
Conn_01x03 | JGPIO7,JGPIO9 | Connector_PinHeader_2.54mm:PinHeader_1x03_P2.54mm_Vertical | own
RP2040_1 | JRP2040R_1 | Connector_PinSocket_2.54mm:PinSocket_1x20_P2.54mm_Vertical | own
RP2040_2 | JRP4020L_1 | Connector_PinSocket_2.54mm:PinSocket_1x20_P2.54mm_Vertical | own
Conn_02x03_Odd_Even | J_I1,J_II1,J_III1,J_IV1,J_V1,J_VI1,J_VII1 | Connector_PinSocket_2.54mm:PinSocket_2x03_P2.54mm_Vertical | own
Conn_02x09_Odd_Even | J_IX1,J_X1 | Connector_PinSocket_2.54mm:PinSocket_2x09_P2.54mm_Vertical | own
Conn_02x12_Odd_Even | J_VIII1 | Connector_PinSocket_2.54mm:PinSocket_2x12_P2.54mm_Vertical | own
10k | R1,R2,R3,R4,R11,R12,R13,R14,R15,R16,R28,R29,R30,R31,R32,R33,R34,R35,R36,R37,R38,R39,R40,R41,R42,R43 | Resistor_SMD:R_0805_2012Metric_Pad1.20x1.40mm_HandSolder | CRCW080510K0FKEBC
330 | R10 | Resistor_SMD:R_0805_2012Metric_Pad1.20x1.40mm_HandSolder | 603-RT0805FRE07330RL
22k | R17,R18,R21,R22 | Resistor_SMD:R_0805_2012Metric_Pad1.20x1.40mm_HandSolder | 756-WCR0805-22KFI
47k | R19,R20,R26,R27 | Resistor_SMD:R_0805_2012Metric_Pad1.20x1.40mm_HandSolder | 603-AC0805FR-1347KL
470 | R7,R9 | Resistor_SMD:R_0805_2012Metric_Pad1.20x1.40mm_HandSolder | 71-CRCW0805470RFKEAC
240 | R8 | Resistor_SMD:R_0805_2012Metric_Pad1.20x1.40mm_HandSolder | 71-CRCW0805240RFKEA
R_Potentiometer_Trim | RV1 | Potentiometer_THT:Potentiometer_Bourns_3299W_Vertical | 652-3299W-1-102LF
SW_Push | SW1 | Button_Switch_THT:SW_PUSH_6mm | own
LM317_TO-220 | U1 | Package_TO_SOT_THT:TO-220-3_Horizontal_TabDown | own
TPA6112A2DGQ | U3 | Package_SO:HVSSOP-10-1EP_3x3mm_P0.5mm_EP1.57x1.88mm_ThermalVias | own
TS5A2234 | U4 | Package_SO:VSSOP-10_3x3mm_P0.5mm | own

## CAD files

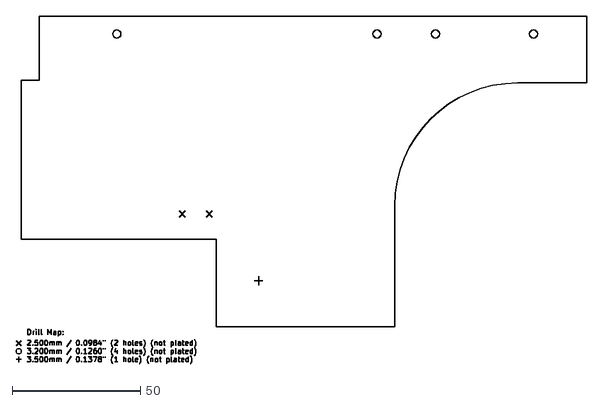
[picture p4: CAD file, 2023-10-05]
03_Development/Hardware/Proto_Bluetooth/Board_production/gerber_files/Board_Bluetooth_radio_platform-NPTH-drl_map.dxf
222.6 x 135.5

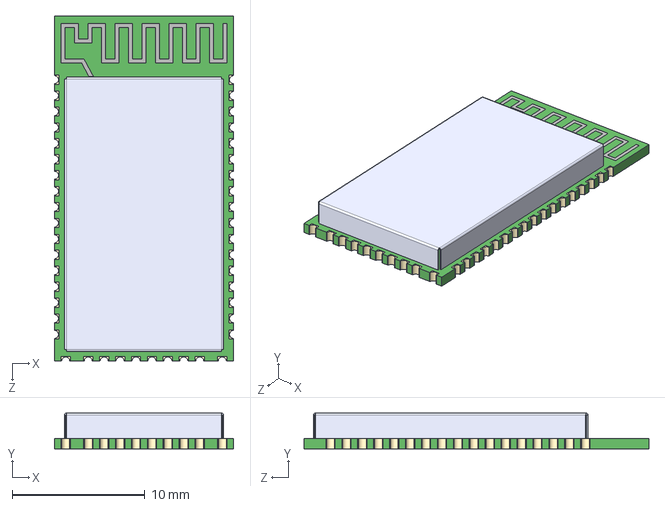
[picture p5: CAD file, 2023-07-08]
03_Development/Hardware/Proto_Bluetooth/Custom_Libraries/MOUDLE-BLUETOOTH-AUDIO-RN52-I_RM_50P-26X13.5MM_/MOUDLE-BLUETOOTH-AUDIO-RN52-I_RM_50P-26X13.5MM_.step
13.5 x 2.70 x 26.0 mm

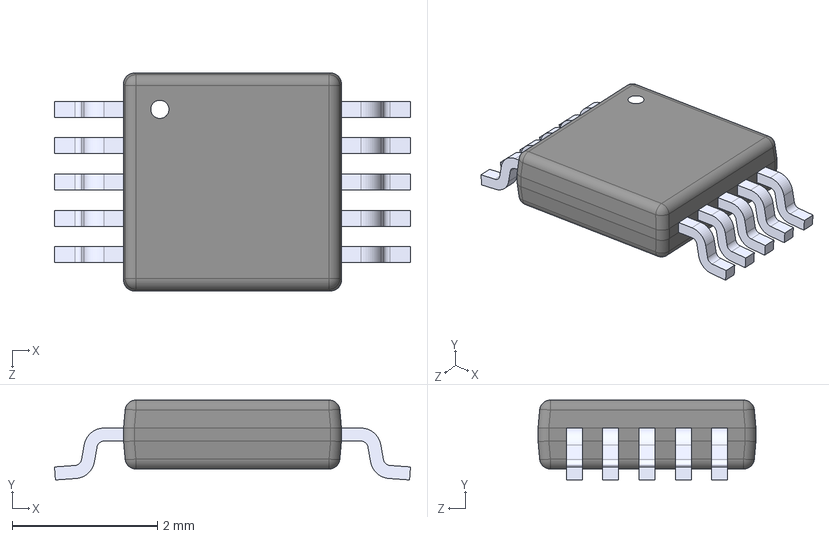
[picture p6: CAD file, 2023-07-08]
03_Development/Hardware/Proto_Bluetooth/Custom_Libraries/TPA6112A2DGQ/TPA6112A2DGQ.step
4.90 x 1.10 x 3.00 mm

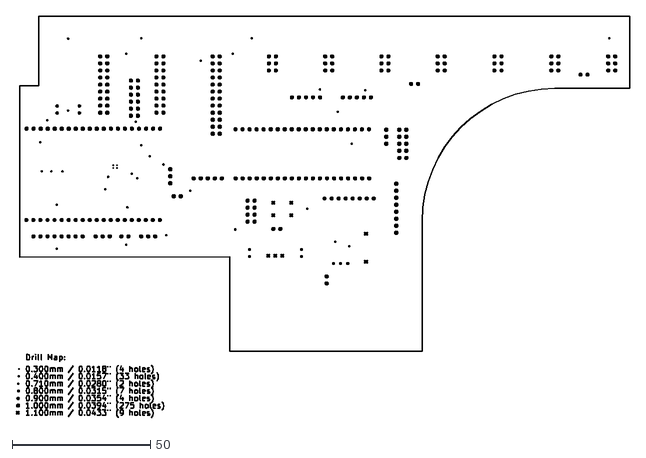
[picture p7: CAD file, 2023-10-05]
03_Development/Hardware/Proto_Bluetooth/Board_production/gerber_files/Board_Bluetooth_radio_platform-PTH-drl_map.dxf
221.7 x 145.0

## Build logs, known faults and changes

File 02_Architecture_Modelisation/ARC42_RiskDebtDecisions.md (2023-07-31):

# Architecture decisions, risks and technical debts

This chapter gathers technical decisions made, why it was decided like that and so on. Some of those decisions were already half explained earlier. This chapter regroups them cleanly

## Technical (architecture) decisions

- Program with mainly be written in C as the whole Pico SDK is available in C, as well as other third party source code. C++ is quite strong, but a well used C is as powerful as C++ and presents the advantage of having a really close to hardware language (even if C++ do provide "low layers", the intensive use of object oriented programming may become an anti-pattern).  

- No AirPlay. Maybe in a second version. But in a first one, use Bluetooth is plenty enough for a fun use of this radio. Many nomad radios also implement only Bluetooth.  

- No Bluetooth low energy. Simply because I wanted to use this old chip I have and because it is enough for the need presented.  

- No AM demodulation. Simply because it is almost never used anymore. Even if it still possible to capture radiowaves from the other side of Europa.  

- The old electronic board will be fully replaced. A first try, using the old AB audio amplifier and FM demodulation was not a success as the technologies doesn't perfectly matches. Indeed, an annoying PIIIIIP was to be heard when playing from Bluetooth stream, using old AB amplifier. Debug it on a hardware point of view may be quick, as it may be VERY long (contradicting organizational constraints).

- No RTOS in a first version, running program on one core seems good. But having fun with hard or soft RTOS with preemptive tasking, is the next step in pipe. For example, RDS decoding could be done on Core1, while rest of code is on Core0. Because RDS is a long parallel task, which may require quite the processing to correct errors.

- Hardware sub-modules are mainly pre-made PCBs, from either Sparkfun or other producers. It reduces HW instability risks.

## Risks

- E-paper has a disadvantage in outdoor, as it doesn't like the sun (as I read). It may be possible to have to switch to another screen, which is more outdoor oriented.

- Bluetooth chip is acutally obsolete and may have to be changed when the old Bluetooth 2.1 will not be supported on new Smartphones. Indeed, Bluetooth evolve quite fast and it could be in a close future that this project can't connect to new Smartphones anymore. The risk is medium, but correction is quite easy, as Bluetooth chip will be mounted on a unpluggable PCB, with a lot of pins.

- Mechanical fit: there is no documentation (or you have to pay) for mechanical dimensions of PCB. This PCB has however to be fixed on ŕadio case, so that push buttons on the top works. And also, a moving PCB in the boxing is not quite recommended. Fixing hole may have to be done/adapted manually, after PCB is produced.

## Technical debt

- A clean RDS decoding, with error correction still have to be done, so that FM module will be fun to use. This part is not tricky, but requires a little bit of time to be stable.

- Clean and powerful use of RP2040 double core system still to be done. Exploit it with FreeRTOS.

- Rotary encoders are actually of poor quality and doesn't present a good A and B signals. Sometimes turing directly procures an indirect turn. Even with resistors and capacitors, on oscilloscope signals aren't always clean.

- Footprint of different modules is quite huge and PCB is on a mechanical point of view, almost full. RP2040 pins are all used and add other devices may be difficult. Remove "sub-pcb" modules and put RP2040, as well as FM, BT modules could be directly installed on PCB.

[< prev (Architecture design)](./ARC42_architectureMain.md)

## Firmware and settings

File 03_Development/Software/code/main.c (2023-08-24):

/**
 * @file    main.c
 * @author  Kureciplatek (galleej@gmail.com)
 * @brief
 * @version 0.1
 * @date 2  023-03-02
 *
 * @copyright Copyright (c) 2023
 * 
 * run gdb server on Raspberry Debug probe:
 * sudo openocd -f interface/cmsis-dap.cfg -f target/rp2040.cfg -c "adapter speed 5000"
 *
 * run gdb on other side:
 * gdb-multiarch prog.elf
 */

/* C standard library */
#include <pico/stdlib.h>
#include <stdio.h>

/* Project includes */
#include "si470x_application.h"
#include "bt_rn52_application.h"
#include "ep_application.h"
#include "re_application.h"
#include "hal_main.h"

/* HW includes */
#include "hardware/gpio.h"

#define GPIO_FM_MODE 27 /* GPIO connected to upper exclusives buttons. It sets the active mode */
#define GPIO_BT_MODE 26 /* GPIO connected to upper exclusives buttons. It sets the active mode */
/* GPIO to activate or deactivate hardware module, depending on modes
 * If high, BT deactivated, FM activated
 * If low,  FM deactivated, BT activated 
 * It will also change analog audio switch to the correct position 
 */
#define GPIO_MODE_HW 22
#define LED_PIN      25 /* LED on Pico Board. It takes no further GPIO on board */


/* _______________________________________________________ */
/*                   APPLICATION SOFTWARE                  */
typedef enum
{
   RADIO_STATE_BT = 0,
   RADIO_STATE_FM,
   RADIO_STATE_IDLE,
   /* Keep at the end */
   RADIO_STATE_MAX
} RADIO_STATE;

/**
 * @brief Initialize Radio hardware, core and interfaces
 */
static void radio_init(void);

/**
 * @brief Get state of radio by reading which button on upper side
 * is currently active 
 */
static void radio_getMode(void);

/**
 * @brief Main radio state machine
 *
 */
void radio_SM(void);

RADIO_STATE radioState;
re_appli_handle *re1;
re_appli_handle *re2;


/**
 * @brief main function
 */
int main(void)
{
   stdio_init_all();

   /* Wait for HW to stabilize - may be measured if can be shorter */
   DEV_Delay_ms(50);

   /* Initialize radio and its modules as wished */
   radio_init();

   printf("################## Start Prog ##################\n");
   while (true)
   {
      /* Infinite loop */
      radio_SM();
      sleep_ms(10);
   }

   return 0;
}

void radio_SM(void)
{
   /* Poll activated mode (gpio) */
   radio_getMode();

   /* Execute radio main state machine to process the last inputs */
   switch (radioState)
   {
   case RADIO_STATE_BT:
      /* Process input */
      bt_processInputs();

      /* Rotary Encoder 1 - actions */
      if (true == re1->tokenIndirect)
      {
         bt_sendCommand(RN52_CMD_VOLUP);
         re1->tokenIndirect = false;
         printf("Send vol+\n");
      }

      if (true == re1->tokenDirect)
      {
         bt_sendCommand(RN52_CMD_VOLDWN);
         re1->tokenDirect = false;
         printf("Send vol-\n");
      }

      if (true == re1->tokenPush)
      {
         bt_sendCommand(RN52_CMD_PLP);
         re1->tokenPush = false;
         printf("Send play pause\n");
      }

      /* Rotary Encoder 2 - actions */
      if (true == re2->tokenIndirect)
      {
         bt_sendCommand(RN52_CMD_NXT);
         re2->tokenIndirect = false;
         printf("NextTrack\n");
         bt_sendCommand(RN52_CMD_TRACK);
      }

      if (true == re2->tokenDirect)
      {
         bt_sendCommand(RN52_CMD_PRV);
         re2->tokenDirect = false;
         printf("PrevTrack\n");
         bt_sendCommand(RN52_CMD_TRACK);
      }

      if (true == re2->tokenPush)
      {
         bt_sendCommand(RN52_CMD_PLP);
         re2->tokenPush = false;
         printf("Send play pause 2\n");
      }
      break;

   case RADIO_STATE_FM:
      /* Process inputs */
      fm_stateMachine();

      /* Rotary Encoder 1 - actions */
      if (true == re1->tokenIndirect)
      {
         fm_setVolume(true);
         re1->tokenIndirect = false;
      }

      if (true == re1->tokenDirect)
      {
         fm_setVolume(false);
         re1->tokenDirect = false;
      }

      if (true == re1->tokenPush)
      {
         fm_toggleMute();
         re1->tokenPush = false;
      }

      /* Rotary Encoder 2 - actions */
      if (true == re2->tokenIndirect)
      {
         fm_startSeekChannel(0x01);
         re2->tokenIndirect = false;
      }

      if (true == re2->tokenDirect)
      {
         fm_startSeekChannel(0x00);
         re2->tokenDirect = false;
      }

      if (true == re2->tokenPush)
      {
         /* @todo Implement big state machine of frequency/station selecting */
      }
      break;

   default:
      break;
   }
}

void radio_init(void)
{
   radioState = RADIO_STATE_IDLE;

   uint32_t ptrRE1 = 0x00;
   uint32_t ptrRE2 = 0x00;

   /* Init GPIOs */
   hal_initGPIOs();
   
   /* Rotary Encoders init */
   re_initModule();

   /* FM module init */
   fm_init();

   /* Bluetooth module init */
//   bt_init();

   /* e-Paper module init */
//   ep_init();

   /* Set Pico Board LED ON */
   gpio_init(LED_PIN);
   gpio_set_dir(LED_PIN, GPIO_OUT);
   gpio_put(LED_PIN, 1);

   /* Radio get mode configuration (2 pins which are not module specific) */
   gpio_init(GPIO_BT_MODE);
   gpio_init(GPIO_FM_MODE);
   gpio_set_dir(GPIO_BT_MODE, GPIO_IN);
   gpio_set_dir(GPIO_FM_MODE, GPIO_IN);

   /* Radio output mode hardware activation. 
    It will activate or deactivate FM or BT hardware modules */
   gpio_init(GPIO_MODE_HW);
   gpio_set_dir(GPIO_MODE_HW, GPIO_OUT);
   gpio_put(GPIO_MODE_HW, 0); /* Bluetooth module per default */

   /* Check Rotary Encoders*/
   re_getHandles(&ptrRE1, &ptrRE2);
   re1 = (re_appli_handle *)ptrRE1;
   re2 = (re_appli_handle *)ptrRE2;
}

static void radio_getMode(void)
{
   if(0 < gpio_get(GPIO_BT_MODE))
   {
      if(RADIO_STATE_BT != radioState)
      {
         printf("Mode BT\n");
         ep_write(EPAPER_PLACE_ACTIVEMODE, 0, "Bluetooth activated", false);
         ep_write(EPAPER_PLACE_ACTIVEMODE, 2, "Device name: radioLaenggass", false);
         ep_write(EPAPER_PLACE_BT_TRACK,   0, "         Track:", false);
         ep_write(EPAPER_PLACE_BT_TRACK,   2, "         Artist:", false);
         ep_write(EPAPER_PLACE_BT_TRACK,   4, "         Album:", false);
         /* Write down to display */
         ep_flush();

         bt_activate();
         fm_deactivate();

         radioState = RADIO_STATE_BT;
         gpio_put(GPIO_MODE_HW, 1);
      }
   }
   else if(0 < gpio_get(GPIO_FM_MODE))
   {
      if(RADIO_STATE_FM != radioState)
      {
         printf("Mode FM\n");
         ep_write(EPAPER_PLACE_ACTIVEMODE, 0, "FM demodulation", true);

         fm_activate();
//         bt_deactivate();

         radioState = RADIO_STATE_FM;
         gpio_put(GPIO_MODE_HW, 0);
      }
   }
   else
   {
      printf("Mode IDLE\r");
      /* In case of no mode active, clean e-paper */
      ep_deactivate();
      /* Deactivate modules to avoid parasite on/off due to interrupts */
      bt_deactivate();
      fm_deactivate();

      radioState = RADIO_STATE_IDLE;
      gpio_put(GPIO_MODE_HW, 0); /* Bluetooth module per default still active, but not using it */
   }
}

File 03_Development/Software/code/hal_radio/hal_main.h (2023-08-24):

/**
 * @file    hal_main.h
 * @author  Jeremie Gallee (galleej@gmail.com)
 * @brief   Gather all GPIOs (maybe more in future) descriptions and IRQs
 *          It will call callbacks in case of GPIO triggered.
 * @version 0.1
 * @date 2023-08-08
 * 
 * @copyright Copyright (c) 2023
 * 
 */


#ifndef HAL_MAIN_H
#define HAL_MAIN_H

#include <stdio.h>
#include "pico/stdlib.h"
#include "si470x_application.h"
#include "bt_rn52_application.h"
#include "ep_application.h"
#include "re_application.h"

/* ------------ RE module ------------ */
#define RE1_GPIOSW   16 // GPIO 16 of RP2040
#define RE1_GPIOA    18  // GPIO 18 of RP2040
#define RE1_GPIOB    19  // GPIO 19 of RP2040

#define RE2_GPIOSW   17 // GPIO 17 of RP2040
#define RE2_GPIOA    20  // GPIO 20 of RP2040
#define RE2_GPIOB    21  // GPIO 21 of RP2040

/* ------------ FM module ------------ */
#define SI470X_COMM_PIN_GPIO2 6

/* ------------ BT module ------------ */
#define RN52_GPIO2   28 /* GPIO 28 for rn52's gpio2 notification pin */


/**
 * @brief Init all GPIOs
 */
void hal_initGPIOs(void);

/**
 * @brief Callback to call if ANY GPIO IRQ was triggered. It will call 
 *        corresponding module callback depending on which GPIO was triggered
 * 
 * @param gpio    [in] uint  which GPIO was triggered
 * @param events  [in] uint32_t what kind of event happened
 */
void hal_gpioCallback(uint gpio, uint32_t events);

void hal_deactivateFM(void);
void hal_deactivateBT(void);
void hal_activateFM(void);
void hal_activateBT(void);

#endif

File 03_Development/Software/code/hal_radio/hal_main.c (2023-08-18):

/**
 * @file    hal_main.c
 * @author  Jeremie Gallee (galleej@gmail.com)
 * @brief   Gather all GPIOs (maybe more in future) descriptions and IRQs
 *          It will call callbacks in case of GPIO triggered.
 * @version 0.1
 * @date 2023-08-08
 * 
 * @copyright Copyright (c) 2023
 * 
 *    "LEVEL_LOW",  // 0x1
 *    "LEVEL_HIGH", // 0x2
 *    "EDGE_FALL",  // 0x4
 *    "EDGE_RISE"   // 0x8
 * 
 */

#include "hal_main.h"

void hal_initGPIOs(void)
{

   /* ------------------------------- RN52 ------------------------------- */
   gpio_init(RN52_GPIO2);
   gpio_set_dir(RN52_GPIO2, GPIO_IN);
   gpio_set_irq_enabled_with_callback(RN52_GPIO2, GPIO_IRQ_EDGE_FALL, true, &hal_gpioCallback);

   /* ------------------------------- SI470X ------------------------------- */
   /* Declare callback of GPIO2*/
   gpio_init(SI470X_COMM_PIN_GPIO2);
   gpio_set_dir(SI470X_COMM_PIN_GPIO2, GPIO_IN);
   gpio_set_irq_enabled(SI470X_COMM_PIN_GPIO2, GPIO_IRQ_EDGE_FALL, true);

   /* ------------------------------- Rotary encoders ------------------------------- */
   gpio_set_irq_enabled(RE1_GPIOA,  GPIO_IRQ_EDGE_RISE, true);
   gpio_set_irq_enabled(RE1_GPIOB,  GPIO_IRQ_EDGE_RISE, true);
   gpio_set_irq_enabled(RE1_GPIOSW, GPIO_IRQ_EDGE_RISE, true);

   gpio_set_irq_enabled(RE2_GPIOA,  GPIO_IRQ_EDGE_RISE, true);
   gpio_set_irq_enabled(RE2_GPIOB,  GPIO_IRQ_EDGE_RISE, true);
   gpio_set_irq_enabled(RE2_GPIOSW, GPIO_IRQ_EDGE_RISE, true);
}

void hal_deactivateBT(void)
{
   gpio_set_irq_enabled(RN52_GPIO2, GPIO_IRQ_EDGE_FALL, false);
}

void hal_deactivateFM(void)
{
   gpio_set_irq_enabled(SI470X_COMM_PIN_GPIO2, GPIO_IRQ_EDGE_FALL, false);
}

void hal_activateBT(void)
{
   gpio_set_irq_enabled(RN52_GPIO2, GPIO_IRQ_EDGE_FALL, true);
}

void hal_activateFM(void)
{
   gpio_set_irq_enabled(SI470X_COMM_PIN_GPIO2, GPIO_IRQ_EDGE_FALL, true);
}

void hal_gpioCallback(uint gpio, uint32_t events)
{
   if ((GPIO_IRQ_EDGE_FALL == events) && (RN52_GPIO2 == gpio))
   {
      rn52_handleGpio2();
   }
   if ((GPIO_IRQ_EDGE_FALL == events) && (SI470X_COMM_PIN_GPIO2 == gpio))
   {
      fm_si470xGpio2_callback();
   }

   if(GPIO_IRQ_EDGE_RISE == events)
   {
      switch (gpio)
      {
      case RE1_GPIOA:
         irqhandlerRE1A();
         break;
      case RE1_GPIOB:
         irqhandlerRE1B();
         break;
      case RE1_GPIOSW:
         irqhandlerRE1SW();
         break;
      case RE2_GPIOA:
         irqhandlerRE2A();
         break;
      case RE2_GPIOB:
         irqhandlerRE2B();
         break;
      case RE2_GPIOSW:
         irqhandlerRE2SW();
         break;
      
      default:
         break;
      }
   }
}

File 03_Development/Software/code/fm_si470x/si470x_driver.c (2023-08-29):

/**
 * @file    si470x_api.c
 * @author  Kureciplatek (galleej@gmail.com)
 * @brief   Driver API to use Si470x module from upper application layers. 
 *          Use it to seek/tune FM radio stations, get RDS data and more.
 *          It needs some RP2040 SDK modules/libraries
 * @version 0.1
 * @date    2023-02-17
 * 
 * @copyright Copyright (c) 2023
 * 
 */
#include "si470x_comm.h"
#include "si470x_driver.h"
#include <math.h>
#include <string.h>
#include <stdio.h>

/**
 * @TODO add following features:
 *
 * ______________________________________
 * - Chip ID, rev and concstructor check: verify it has RDS and is good
 * - get RSSI bits (STATUSRSSI register) -> Furnishes RSSI level 
 * (nice to see, poll it for smooth pulse on HMI)
 * - RDS/RBDS supported  -> Check for API config & state machine
 * - AGCD Automatic Gain Control -> Actually, better keep it on
 * - ST stereo indicator (ST bit) -> maybe do it, but we have mono output, what for? 
 * - BLNDADJ Stereo goes with with -> feature to be checked
 *
 * ______________________________________
 * SHOULD BE CHECKED:
 * - RDSM: RDS mode (verbose or not)
 * - RDSIEN: RDS Interrupt ENable  (on GPIO2)
 * - STCIEN: Seek Tune Complete Interrupt ENable (on GPIO2)
 * 
 * ______________________________________
 * UNCHECKED that could be good to add:
 * - AFCRL AFC Rail (automatic frequency control) 1 = AFC railed, indicating an invalid channel
 * Using the RSSI threshold in conjunction with AFC rail offers seek performance 
 * with a greater than 90% probability of finding only valid stations
 * - AHIZEN (audio high Z enable) for electronic output protection purpose? To be checked
 * - SF/BL
 * - RDSR   RDS group Ready
 * - RDSS   RDS synchronized. Available only in RDS Verbose mode
 * 
 * ______________________________________
 * rework way to configure region, and the different Si470x chips: some have
 * RDS/RBDS, some not.
 * 
 * 
 * @WARNING, check status with restart seek/tune when flag is not resetted in Si470x memory
 * ANSWER -> Do not set the TUNE or SEEK bits until the Si470x clears the STC bit.
 */

// change this to configure FM band, channel spacing, and de-emphasis
#define RADIO_ID_STR_SIZE 5

#define SI4703_REG_SIZE_BYTES       32
#define SI4703_REG_RDS_SIZE_BYTES   8

#define TUNE_POLL_INTERVAL_MS 20U
#define SEEK_POLL_INTERVAL_MS 200U // relatively large, to reduce electrical interference from I2C

/* ___ Region configurations and sensitivity presets description ____ */
/* SEEKTH, SKSNR, SKCNT */
static const seekSens_presets_t seekSensPresets[] =
{{0x19, 0x00, 0x00}, /* FM_SEEK_SENSITIVITY_DEFAULT */
 {0x19, 0x04, 0x08}, /* FM_SEEK_SENSITIVITY_RECOMMENDED */
 {0x0C, 0x04, 0x08}, /* FM_SEEK_SENSITIVITY_MORE */
 {0x0C, 0x07, 0x0F}, /* FM_SEEK_SENSITIVITY_GOOD_QUALITY */
 {0x00, 0x04, 0x0F}  /* FM_SEEK_SENSITIVITY_MOST */
};

/* BOTTOM , TOP */
static const fm_freqRange_t bandRegions[] = 
{{87.5f, 108.0f}, /* FM_BAND_USAEUROPE */
 {76.0f, 108.0f}, /* FM_BAND_JAPAN_WIDE */
 {76.0f, 90.0f }    /* FM_BAND_JAPAN */
};

/* FREQ SPACE */
static const float spacingRegions[] = 
{0.2f,   /* FM_CHANNEL_SPACING_200 Americas, South Korea, Australia. */
 0.1f,   /* FM_CHANNEL_SPACING_100  Europe, Japan. */
 0.05f,  /* FM_CHANNEL_SPACING_50   Italy. */
};

/* Handle to Si470x module, gathers all needed info and registers */
si470x_t _radioHandle;

///////////////////// PUBLIC FUNCTIONS DEFINITIONS /////////////////////////////
/* _______________ START AND CONFIG _______________ */
void si470x_init(void) 
{
   printf("[FM][DRV] init fm module\n");
   uint8_t index = 0x00;
   uint16_t regVal = 0x0000;
   
   /* Init hardware communication line for Si470x module */
   si470x_comm_initHW();

   /* reset memory where _radioHandle is placed to 0 */
   memset(&_radioHandle, 0, sizeof(si470x_t));

   /* Set EUROPE configuration */
   _radioHandle._config.band                 = FM_BAND_USAEUROPE;
   _radioHandle._config.channel_spacing      = FM_CHANNEL_SPACING_100;
   _radioHandle._config.deemphasis           = FM_DEEMPHASIS_50;
   /* Set default FM softmute technic and sensitivity */
   _radioHandle._config.seek_sensitivity     = FM_SEEK_SENSITIVITY_RECOMMENDED;
   _radioHandle._config.softmute_rate        = FM_SOFTMUTE_FASTEST;
   _radioHandle._config.softmute_attenuation = FM_SOFTMUTE_ATTENUATION_16;

   /* Set default frequency with region presets as bottom spectrum freq */
   _radioHandle._freq      = bandRegions[_radioHandle._config.band].bottom;
   _radioHandle._mute      = false;
   _radioHandle._softmute  = true;
   _radioHandle._mono      = true;  /* start in mono, better SNR */
   _radioHandle._volext    = false; /* High volume range */
   _radioHandle._volume    = SI4703_MAX_VOLUME;
   
   /* All Si470x registers values (shadow) should be 0 */
   while((index < SI470x_REG_MAX) &&( 0x0000 == regVal))
   {
      regVal = _radioHandle._regs[index];
      if(0x0000 != regVal) {printf("[FM][DRV] ERROR - one shadow reg not 0x0000 (Reg%d=0x%04x\n", index, regVal);}
      index++;
   };
   
   /* Power up FM module, to power it down, call fm_deInit() or si470x_powerDown() */
   _radioHandle._state = SI470X_STATE_INITIALIZED;
//   si470x_powerUp();  /* No automatic power up. Wait for FM to be activated */
   printf("[FM][DRV] INIT - radio init finished\n");
}
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

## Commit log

2023-07-08 [SYS_8] Fixed remote repo with Github
    Use of github as remote repo for versioning and backup purpose
    Use of ssh is strange as key looked to be changed. Maybe nothing
    dangerous.
    Other drawback: lost of old git story. Look how to do it
    [Board_Bluetooth_radio_platform.kicad_pcb, Board_Bluetooth_radio_platform.kicad_sch, BtRadio_audioAmplifier.kicad_sch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]
2023-07-10 [SFW_4] Add rotary encoder module structure
    Need to add interrupt on RP2040 though. State machine and handlers finished
2023-07-11 [SFW_4] Add interrupt description on gpios
    Define GPIOs of rotary encoders as interrupt. There are some
    elements, like the fact that interrupt are CORE linked which
    should be checked. Add of all interrupt callbacks
    Test ready
2023-07-13 [SFW_11] Delay on RE ready to test
    Maybe add a timeout before gpioA or gpioB may react
    should be added to filter mechanical vibration noise
    on REs
    [main.c, si470x_api.c, si470x_application.c]
2023-07-14 [SFW_17] Add capture of uart data from rn52
    Reindent re_application
    Compress all bt command functions API into one sendCmd()
2023-07-17 Cleanup code of FM module
    FM module may contain a bug quite long to solve. Therefore
    for project to carry on, deactivate this module in a first
    phase and focus on bt+epaper+pcb as it still has issues
    to be solved
    [bt_rn52_application.c, si470x_api.c, si470x_application.c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]
2023-07-17 [SFW_18] Fixed FM refactoring
    Rename of _api to _driver as it is an si470x driver
    Split between fm relevant and si470x functions
    Cleanup some part of code for cleaner algorothms
    [main.c, si470x_application.c, si470x_comm.c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]
2023-07-18 [SFW_5] Fix clean hierarchical architecture of SW
    A main state machine in main.c module calls the other ones
    processes their new inputs and order actions depending on
    the last events.
    Only FM and BT module have those sub-state machines
    [bt_rn52_application.c, main.c]
2023-07-18 [SFW_9] Fix Bluetooth connection status > > Simply poll status register connection bit state. If cleared > then ready to pair, otherwise, we are connected
    [bt_rn52_application.c]
2023-07-24 [SFW_20] Fix project compilation
    Project now fully compiles with CMake. Had to move all epaper
    lib files into one subfolder for simplicity.
    GPIO interrupt are done the simpliest way but have to be checked
    Add of RE CMakeLists.txt file
    [DEV_Config.c, bt_rn52_application.c]
2023-07-25 [HDW_29] Fixed LM317 heatsink PCB space
    LM317 has a heeatsink in case of too much power disspation.
    Its sie is approximately 20x20 mm and has influence on
    mechanical place of other components.
    Moved power supply unit so that all is good
    [Board_Bluetooth_radio_platform.kicad_pcb, Board_Bluetooth_radio_platform.kicad_sch]
2023-07-25 [HDW_31] Fixed add of trim resistance
    Power supply with LM317 is not always perfect with
    10% resistances. Add of potentiometer to get better
    3.3 V values
    [Board_Bluetooth_radio_platform.kicad_pcb, Board_Bluetooth_radio_platform.kicad_sch]
2023-07-25 [HDW_31] Add 1205V DC DC converter
    Add of a murata NXE2S1205MC DC DC downconverter
    to add 12V power supply possibility. Will maybe
    not be soldered but footprints are there for
    future amelioration. Helps to plug a battery
    on radio
    [Board_Bluetooth_radio_platform.kicad_pcb, Board_Bluetooth_radio_platform.kicad_sch]
2023-07-26 [HDW_36] Fixed edge cut layer
    Edge.cut layer fixed with circle removed
    Cleanup TICKET.md file
    minor other correction
    READY TO TEST. All firmware should be tested
    on breadboard first before sending to production
    [Board_Bluetooth_radio_platform.kicad_pcb, Board_Bluetooth_radio_platform.kicad_sch]
2023-07-27 Add pictures and remove epaper connector in schematics
    Schematic of epaper was pointless as alone in its file. Moved to main schematic
    Add pictures of schematic and PCB for documentation
    [Board_Bluetooth_radio_platform.kicad_pcb, Board_Bluetooth_radio_platform.kicad_sch, BtRadio_audioPreamplifier.kicad_sch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]
2023-07-29 [SYS_12] Add markdown files for ARC42 architecture
    Use of ARC42 to write down all algorithms and structure as
    well as describe project
    Add of PCB and schematic pictures
2023-07-29 [SYS_12] Add contextes and solution strategy
    Technical solution selected and described for all sub-modules
    Add if business and technical contextes diagrams
    Add a consumption estimation and working time of project on a
    battery
2023-08-02 [HDW_25] Fix mounting holes issue
    Add mounting holes for screwing to radio chassis
    Add mounting holes for PAM8302
    Cleanup TICKETS file
    Change README name
    [Board_Bluetooth_radio_platform.kicad_pcb, Board_Bluetooth_radio_platform.kicad_sch]
2023-08-03 [SYS_11] PCB PRODUCTION
    Send PCB to production
    Minor changes to other files
    Add Gerber production files, BOM and POS files
    [Board_Bluetooth_radio_platform-B_Cu.gbr, Board_Bluetooth_radio_platform-B_Mask.gbr, Board_Bluetooth_radio_platform-B_Paste.gbr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]
2023-08-03 [HDW_37] Add files for production
    Add JLCPCB form BOM and own format BOM for mouser ref tracking
    Minor correction on schematic: J16 -> J_VIII1
    [Board_Bluetooth_radio_platform.kicad_sch, Board_Bluetooth_radio_platform_JLCPCB_BOM.csv, Board_Bluetooth_radio_platform_OWN_BOM.csv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]
2023-08-08 [SYS_11] Fix rotary encoders and GPIO interrupts
    Use of gpio_set_irq_enabled_with_callback one time to declare gpio irq callback
    Then use gpio_set_irq_enabled() to activate IRQ callback on specific GPIO
    Put all this behavior in one file only: hal_main
    One rotary encoder still has some glitches, maybe electronic
    Now go to sleep
    [bt_rn52_application.c, hal_main.c, hal_main.h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]
2023-08-08 [SYS_11] Fix Bluetooth module comm
    UART is wrongly wired and must be changed. It actually
    needs wires on GPIO 4 and 5
    Update must be done on schematic and board
    [bt_rn52_application.c]
2023-08-08 [HDW_38] Fix Bt communication wires
    Bluetooth Rx pin connected to GPIO4 of RP240
    Bluetooth Tx pin connected to GPIO5 of RP2040
    [Board_Bluetooth_radio_platform.kicad_pcb, Board_Bluetooth_radio_platform.kicad_sch, Board_Bluetooth_radio_platform_OWN_BOM.csv]
2023-08-10 [HDW_39] Fix pull ups and pull down resistances
    RP2040 internal's pull up/down are actually 80 kOhms
    which is quite few. ALl filters and external pull up-down
    are too high for them and incoming signal on RP2040
    is too small.
    Set all to either 4.7 kOhms or 10 kOhms
    [Board_Bluetooth_radio_platform.kicad_sch, BtRadio_audioAmplifier.kicad_sch, BtRadio_phillipsConnectors.kicad_sch]
2023-08-10 [SFW_25] Fix clean of lines on e-Paper
    [bt_rn52_application.c, hal_main.c, main.c]
2023-08-15 [SFW_13] FIX RN52 GPIO2 interrupt
    RN52 set its GPIO2 to low when internal status of
    Bluetooth chip changes.
    [hal_main.c]
2023-08-15 [SFW_25] FIX cleanup of epaper when shutting down
    It is actually not automatic when shutting radio down
    but it brings the possibility to clear e-paper with a
    combination of buttons. Use it before removing power
    from radio
    [main.c]
2023-08-15 FIX required xml file for KiCad
    KiCad EDA bases its project on an XML files for all different
    schematics and files. Forgot to add it to versioning
2023-08-17 [SFW_17] FIX RN52 comm and instabilities
    FIX CMakeLists.txt as it was pointing to wrong SDK path
    ADD RN52 uart communication cleaning functions and processing
    FIX panic between epaper and delay functions. sleep_ms was called
    inside of an interrupt (imer alarm) which produces a panic
    Call process of UART buffer asynchronus
    [bt_rn52_application.c, hal_main.c, main.c]
2023-08-17 UPGRADE view of track metadata
    Add of title lines for what is written and also
    album is now to be seen
2023-08-18 [SFW_28] ADD activation and deactivation of BT and FM modules
    Disable interrupts of unused module to avoid perturbations
    while running one audio interface.
    [bt_rn52_application.c, hal_main.c, hal_main.h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]
2023-08-24 [SFW_2] FIXED error while seekiing
    When yxou give a pointer to an array to a function and don't
    check if you are not overwriting sensible values, then it can
    be that you overwride the stack itself...
    [DEV_Config.c, hal_main.h, main.c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]
2023-08-29 [SFW_14] FIX wrong deemphasis set
    Deemphasis mask was 0400 instead of 0800 which led to
    bit never be set
    [si470x_application.c, si470x_comm.c, si470x_driver.c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]
2023-09-24 [HDW_41] FIX communication lines to central unit
    FM, EP and BT modules had been routed to ports of RP2040 which don't allow
    UART or I2C and must have been changed
    [Board_Bluetooth_radio_platform.kicad_pcb, Board_Bluetooth_radio_platform.kicad_sch]
2023-09-24 [HDW_45] FIX remove of 12V power supply
    [Board_Bluetooth_radio_platform.kicad_pcb, Board_Bluetooth_radio_platform.kicad_sch]
2023-09-25 [HDW_43] FIX PCB edges for mechanical fit in Radio
    Left side is not fully filled as we need a space for Bluetooth
    antenna's
    Space for loudspeaker had to be increased
    Right upper size had to be reduced of a couple of cm
    Left spaces had some space avaialble which is now used
    Ready for button resync and replace of components
    [Board_Bluetooth_radio_platform.kicad_pcb]
2023-09-25 [HDW_44][HDW_42][HDW_50] FIX all of those topics
    Move mounting hole to their correct place
    Push buttons are good and works as expected
    Place of specific headers for push-buttons is now corrected
    [Board_Bluetooth_radio_platform.kicad_pcb]
2023-09-26 [HDW_49] FIX place of elements for new version
    Remove micro i/o from RN52 as they won't be used
    Move power supply down on PCB
    Move class D amplifier
    Add hole for push buttons mounting
    [Board_Bluetooth_radio_platform.kicad_pcb, Board_Bluetooth_radio_platform.kicad_sch]
2023-09-26 [HDW_51] FIX push button connector
    Push button connector for power supply was not a holding
    one and had to be changed to a holding one
    PCB updated
    Add of GND to some of the headers
    [Board_Bluetooth_radio_platform.kicad_pcb, Board_Bluetooth_radio_platform.kicad_sch, BtRadio_phillipsConnectors.kicad_sch]
2023-09-27 RELEASE CANDIDATE V1.1 of PCB
    All changes required on schematic and PCB are done
    DRC executed
    Minimal finalization of PCB with small correction
    Ready to be tested before prod
    [Board_Bluetooth_radio_platform.kicad_pcb, Board_Bluetooth_radio_platform.kicad_sch, BtRadio_phillipsConnectors.kicad_sch]
2023-10-02 [HDW_54] FIX Bill Of Matierial for V1.1
    FIX footprint of C15 and C16 from 0805 to 1210
    Order all necessary parts from BOM
    [Board_Bluetooth_radio_platform.kicad_pcb, Board_Bluetooth_radio_platform.kicad_sch, Board_Bluetooth_radio_platform_OWN_BOM.csv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]
2023-10-02 [HDW_53] FIX layout of audio preamplifier
    [Board_Bluetooth_radio_platform.kicad_pcb]
2023-10-03 [HDW_55] FIX grounding of PCB for better gnd pane
    [Board_Bluetooth_radio_platform.kicad_pcb, Board_Bluetooth_radio_platform.kicad_sch, BtRadio_phillipsConnectors.kicad_sch]
2023-10-05 PROD Mark II - files sent to production
    Modify mechanical placement of buttons and layout
    Reduction of pull up/down resistances
    Fix communication routing between modules and RP2040
    Fix board size
    Version: V1.1
    [Board_Bluetooth_radio_platform-B_Cu.gbr, Board_Bluetooth_radio_platform-B_Mask.gbr, Board_Bluetooth_radio_platform-B_Silkscreen.gbr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]
